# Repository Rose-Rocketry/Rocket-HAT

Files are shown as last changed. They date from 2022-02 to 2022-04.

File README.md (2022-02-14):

# Rocket-HAT
A Sensor Hat for a raspberry pi with: an IMU, Altimeter, and 5V power protection

# Usage
There are two jumpers on the board; J7 is for powering the hat through the PI. Otherwise, the HAT will get power from the battery while also powering the Pi. J9 is to
enable writing to the EEPROM after manufacture. This EEPROM is for matching with the Raspberry Pi foundation's specs.

There is also a solder bridge for the BNO055. This is in case we have an address conflict and need to change the address from 0x28 to 0x29.

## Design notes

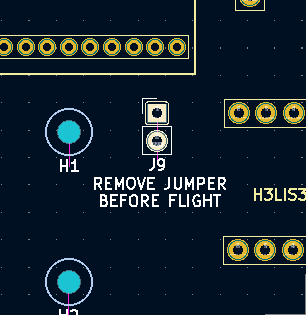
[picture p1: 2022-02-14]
rsc/J9 Screenshot.png

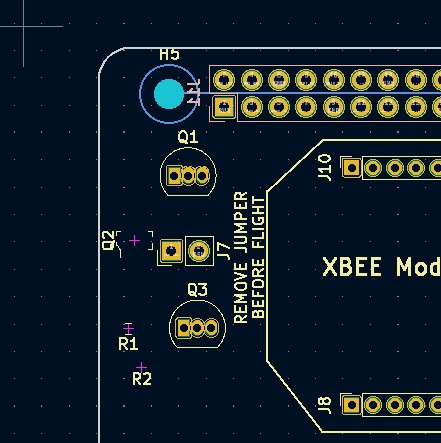
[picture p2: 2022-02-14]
rsc/J7 Screenshot.png

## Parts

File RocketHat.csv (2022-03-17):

Source: | C:\Users\armstrjj\Documents\Custom Electronics\RocketHat\RocketHat.kicad_sch
Date: | 3/3/2022 14:15
Tool: | Eeschema (6.0.0)
Generator: | C:\Program Files\KiCad\6.0\bin\scripting\plugins/bom_csv_grouped_by_value_with_fp.py
Component Count: | 28
Ref | Qnty | Value | Cmp name | Footprint | Description | Vendor | Already Listed
H1, H2, | 2 | MountingHole | MountingHole | MountingHole:MountingHole_2.2mm_M2 | Mounting Hole without connection
H3, H4, H5, H6, | 4 | MountingHole | MountingHole | MountingHole:MountingHole_2.7mm_M2.5 | Mounting Hole without connection
J1, J2, J4, | 3 | Conn_01x06_Female | Conn_01x06_Female | Connector_PinSocket_2.54mm:PinSocket_1x06_P2.54mm_Vertical | Generic connector, single row, 01x06, script generated (kicad-library-utils/schlib/autogen/connector/)
J3, | 1 | Conn_01x07_Female | Conn_01x07_Female | Connector_PinSocket_2.54mm:PinSocket_1x07_P2.54mm_Vertical | Generic connector, single row, 01x07, script generated (kicad-library-utils/schlib/autogen/connector/)
J5, | 1 | Conn_01x04_Female | Conn_01x04_Female | Connector_PinSocket_2.54mm:PinSocket_1x04_P2.54mm_Vertical | Generic connector, single row, 01x04, script generated (kicad-library-utils/schlib/autogen/connector/)
J6, | 1 | Conn_01x02_Female | Conn_01x02_Female | Connector_Wago:Wago_734-162_1x02_P3.50mm_Horizontal | Generic connector, single row, 01x02, script generated (kicad-library-utils/schlib/autogen/connector/) | OSTTE020104 On Shore Technology Inc. | Connectors, Interconnects | DigiKey
J7, J9, | 2 | Conn_01x02 | Conn_01x02 | Connector_PinHeader_2.54mm:PinHeader_1x02_P2.54mm_Vertical | Generic connector, single row, 01x02, script generated (kicad-library-utils/schlib/autogen/connector/) | QPC02SXGN-RC Sullins Connector Solutions | Connectors, Interconnects | DigiKey
J8, J10, | 2 | Conn_01x10_Female | Conn_01x10_Female | Connector_PinSocket_2.00mm:PinSocket_1x10_P2.00mm_Vertical | Generic connector, single row, 01x10, script generated (kicad-library-utils/schlib/autogen/connector/)
J11, | 1 | Raspberry_Pi_2_3 | Raspberry_Pi_2_3 | Connector_PinSocket_2.54mm:PinSocket_2x20_P2.54mm_Vertical | expansion header for Raspberry Pi 2 & 3
JP1, | 1 | SolderJumper_2_Open | SolderJumper_2_Open | Jumper:SolderJumper-2_P1.3mm_Open_TrianglePad1.0x1.5mm | Solder Jumper, 2-pole, open
Q1, Q3, | 2 | 2N3904 | 2N3904 | Package_TO_SOT_THT:TO-92_Inline | 0.2A Ic, 40V Vce, Small Signal NPN Transistor, TO-92 | 2N3904 Galco Industrial Electronics | Discrete Semiconductor Products | DigiKey Marketplace
Q2, | 1 | DMG2305UX-13 | DMG2305UX-13 | digikey-footprints:SOT-23-3 | MOSFET P-CH 20V 4.2A SOT23 | RQ5C035BCTCL Rohm Semiconductor | Discrete Semiconductor Products | DigiKey
R1, R3, | 2 | 10K | R_Small | Resistor_SMD:R_0603_1608Metric | Resistor, small symbol | See Next Link
R2, | 1 | 47K | R_Small | Resistor_SMD:R_0603_1608Metric | Resistor, small symbol | See Next Link
R4, | 1 | 10K 1% | R_Small | Resistor_SMD:R_0603_1608Metric | Resistor, small symbol | See Next Link
R5, R6, | 2 | 3.9K | R_Small | Resistor_SMD:R_0603_1608Metric | Resistor, small symbol | KIT-RMCF0603JT-13 Stackpole Electronics Inc | Kits | DigiKey
U1, | 1 | CAT24C128 | CAT24C128 | Package_SO:SOIC-8_3.9x4.9mm_P1.27mm | 128 kb CMOS Serial EEPROM, SOIC-8/TSSOP-8/DFN-8 | CAT24C128WI-GT3 onsemi | Integrated Circuits (ICs) | DigiKey Marketplace

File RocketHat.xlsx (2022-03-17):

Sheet: RocketHat
Source: | C:\Users\armstrjj\Documents\Custom Electronics\RocketHat\RocketHat.kicad_sch
Date: | 2022-03-03 14:15
Tool: | Eeschema (6.0.0)
Generator: | C:\Program Files\KiCad\6.0\bin\scripting\plugins/bom_csv_grouped_by_value_with_fp.py
Component Count: | 28
Ref | Qnty | Value | Cmp name | Footprint | Description | Vendor | Already Listed
H1, H2, | 2 | MountingHole | MountingHole | MountingHole:MountingHole_2.2mm_M2 | Mounting Hole without connection |  | Y
H3, H4, H5, H6, | 4 | MountingHole | MountingHole | MountingHole:MountingHole_2.7mm_M2.5 | Mounting Hole without connection |  | Y
J1, J2, J4, | 3 | Conn_01x06_Female | Conn_01x06_Female | Connector_PinSocket_2.54mm:PinSocket_1x06_P2.54mm_Vertical | Generic connector, single row, 01x06, script generated (kicad-library-utils/schlib/autogen/connector/) |  | Y
J3, | 1 | Conn_01x07_Female | Conn_01x07_Female | Connector_PinSocket_2.54mm:PinSocket_1x07_P2.54mm_Vertical | Generic connector, single row, 01x07, script generated (kicad-library-utils/schlib/autogen/connector/) |  | Y
J5, | 1 | Conn_01x04_Female | Conn_01x04_Female | Connector_PinSocket_2.54mm:PinSocket_1x04_P2.54mm_Vertical | Generic connector, single row, 01x04, script generated (kicad-library-utils/schlib/autogen/connector/) |  | Y
J6, | 1 | Conn_01x02_Female | Conn_01x02_Female | Connector_Wago:Wago_734-162_1x02_P3.50mm_Horizontal | Generic connector, single row, 01x02, script generated (kicad-library-utils/schlib/autogen/connector/) | OSTTE020104 On Shore Technology Inc. | Connectors, Interconnects | DigiKey (https://www.digikey.com/en/products/detail/on-shore-technology-inc/OSTTE020104/2351816)
J7, J9, | 2 | Conn_01x02 | Conn_01x02 | Connector_PinHeader_2.54mm:PinHeader_1x02_P2.54mm_Vertical | Generic connector, single row, 01x02, script generated (kicad-library-utils/schlib/autogen/connector/) | QPC02SXGN-RC Sullins Connector Solutions | Connectors, Interconnects | DigiKey (https://www.digikey.com/en/products/detail/sullins-connector-solutions/QPC02SXGN-RC/2618262)
J8, J10, | 2 | Conn_01x10_Female | Conn_01x10_Female | Connector_PinSocket_2.00mm:PinSocket_1x10_P2.00mm_Vertical | Generic connector, single row, 01x10, script generated (kicad-library-utils/schlib/autogen/connector/) |  | Y
J11, | 1 | Raspberry_Pi_2_3 | Raspberry_Pi_2_3 | Connector_PinSocket_2.54mm:PinSocket_2x20_P2.54mm_Vertical | expansion header for Raspberry Pi 2 & 3 |  | Y
JP1, | 1 | SolderJumper_2_Open | SolderJumper_2_Open | Jumper:SolderJumper-2_P1.3mm_Open_TrianglePad1.0x1.5mm | Solder Jumper, 2-pole, open |  | Y
Q1, Q3, | 2 | 2N3904 | 2N3904 | Package_TO_SOT_THT:TO-92_Inline | 0.2A Ic, 40V Vce, Small Signal NPN Transistor, TO-92 | 2N3904 Galco Industrial Electronics | Discrete Semiconductor Products | DigiKey Marketplace (https://www.digikey.com/en/products/detail/galco-industrial-electronics/2N3904/15657702)
Q2, | 1 | DMG2305UX-13 | DMG2305UX-13 | digikey-footprints:SOT-23-3 | MOSFET P-CH 20V 4.2A SOT23 | RQ5C035BCTCL Rohm Semiconductor | Discrete Semiconductor Products | DigiKey (https://www.digikey.com/en/products/detail/rohm-semiconductor/RQ5C035BCTCL/6573257)
R1, R3, | 2 | 10K | R_Small | Resistor_SMD:R_0603_1608Metric | Resistor, small symbol | See Next Link
R2, | 1 | 47K | R_Small | Resistor_SMD:R_0603_1608Metric | Resistor, small symbol | See Next Link
R4, | 1 | 10K 1% | R_Small | Resistor_SMD:R_0603_1608Metric | Resistor, small symbol | See Next Link
R5, R6, | 2 | 3.9K | R_Small | Resistor_SMD:R_0603_1608Metric | Resistor, small symbol | KIT-RMCF0603JT-13 Stackpole Electronics Inc | Kits | DigiKey (https://www.digikey.com/en/products/detail/stackpole-electronics-inc/KIT-RMCF0603JT-13/4916518)
U1, | 1 | CAT24C128 | CAT24C128 | Package_SO:SOIC-8_3.9x4.9mm_P1.27mm | 128 kb CMOS Serial EEPROM, SOIC-8/TSSOP-8/DFN-8 | DO NOT USE

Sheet: Final BOM
Item Name | Quanitity | Purchase Link | Price Per Unit | Itemized Cost | Total Order Cost
1608 Metric Resistor Book | 1 | KIT-RMCF0603JT-13 Stackpole Electronics Inc | Kits | DigiKey (https://www.digikey.com/en/products/detail/stackpole-electronics-inc/KIT-RMCF0603JT-13/4916518) | $26.96 | $26.96 | $50.07
RQ5C035BCTCL - P Channel Mosfet | 2 | RQ5C035BCTCL Rohm Semiconductor | Discrete Semiconductor Products | DigiKey (https://www.digikey.com/en/products/detail/rohm-semiconductor/RQ5C035BCTCL/6573257) | $0.45 | $0.90
NPN Transistor 40 | 25 | 2N3904 NTE Electronics, Inc | Discrete Semiconductor Products | DigiKey Marketplace (https://www.digikey.com/en/products/detail/nte-electronics-inc/2N3904/11648305) | $0.11 | $2.70
2-Wire Terminal Block 16-26 AWG | 2 | OSTTE020104 On Shore Technology Inc. | Connectors, Interconnects | DigiKey (https://www.digikey.com/en/products/detail/on-shore-technology-inc/OSTTE020104/2351816) | $0.76 | $1.52
Xbee Header Block Bag of 10 | 1 | Generic 2mm 10 Pin XBee Socket Header(pack of 10) - - Amazon.com (https://www.amazon.com/Generic-XBee-Socket-Header-pack/dp/B00OE92P88) | $7.99 | $7.99
Raspberry Pi Header Socket | 1 | Amazon.com: Adafruit 4079 2 x 20 Socket Riser Header for Raspberry Pi Hats and Bonnets : Electronics (https://www.amazon.com/Adafruit-Socket-Header-Raspberry-Bonnets/dp/B07PPD25MK) | $10.00 | $10.00

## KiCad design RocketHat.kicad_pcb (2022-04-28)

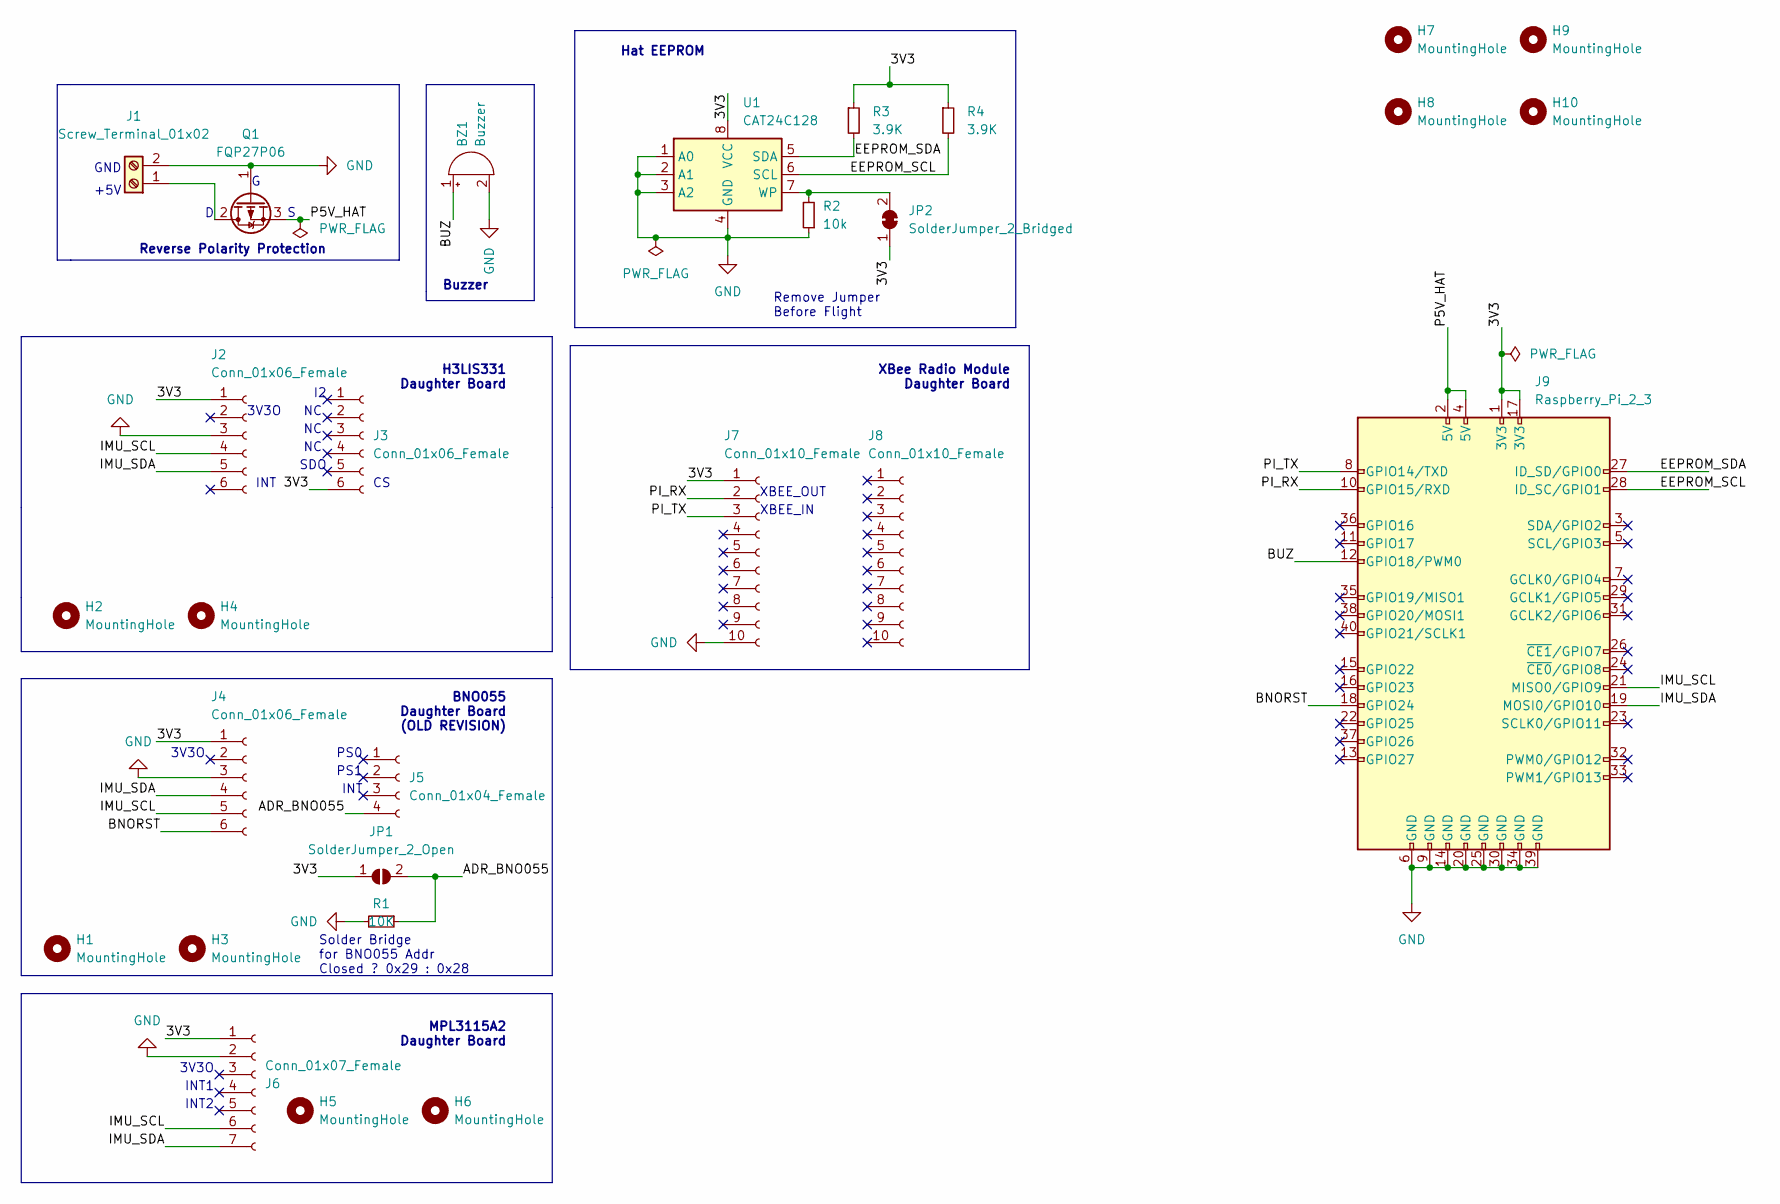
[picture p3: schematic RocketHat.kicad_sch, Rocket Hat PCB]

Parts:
BZ1: Buzzer; Buzzer_TDK_PS1240P02BT_D12.2mm_H6.5mm
H1, H2, H3, H4, H5, H6: MountingHole; MountingHole_2.2mm_M2
H7, H8, H9, H10: MountingHole; MountingHole_2.7mm_M2.5
J1: Screw_Terminal_01x02; TerminalBlock_Phoenix_MKDS-1,5-2_1x02_P5.00mm_Horizontal
J2, J3, J4: Conn_01x06_Female; PinSocket_1x06_P2.54mm_Vertical
J5: Conn_01x04_Female; PinSocket_1x04_P2.54mm_Vertical
J6: Conn_01x07_Female; PinSocket_1x07_P2.54mm_Vertical
J7, J8: Conn_01x10_Female; PinSocket_1x10_P2.00mm_Vertical
J9: Raspberry_Pi_2_3; PinSocket_2x20_P2.54mm_Vertical
JP1: SolderJumper_2_Open; SolderJumper-2_P1.3mm_Open_TrianglePad1.0x1.5mm
JP2: SolderJumper_2_Bridged; SolderJumper-2_P1.3mm_Bridged_RoundedPad1.0x1.5mm
Q1: FQP27P06; TO-220-3_Vertical
R1: 10K; R_Axial_DIN0204_L3.6mm_D1.6mm_P5.08mm_Horizontal
R2: 10k; R_Axial_DIN0204_L3.6mm_D1.6mm_P5.08mm_Horizontal
R3, R4: 3.9K; R_Axial_DIN0204_L3.6mm_D1.6mm_P5.08mm_Horizontal
U1: CAT24C128; SOIC-8_3.9x4.9mm_P1.27mm

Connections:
/3V3: J2.1, J3.6, J4.1, J6.1, J7.1, J9.1 (3V3), J9.17 (3V3), JP1.1 (A), JP2.1 (A), R3.1, R4.1, U1.8 (VCC)
/ADR_BNO055: J5.4, JP1.2 (B), R1.1
/BNORST: J4.6, J9.18 (GPIO24)
/BUZ: BZ1.1 (-), J9.12 (GPIO18/PWM0)
/EEPROM_SCL: J9.28 (ID_SC/GPIO1), R4.2, U1.6 (SCL)
/EEPROM_SDA: J9.27 (ID_SD/GPIO0), R3.2, U1.5 (SDA)
/IMU_SCL: J2.4, J4.5, J6.6, J9.21 (MISO0/GPIO9)
/IMU_SDA: J2.5, J4.4, J6.7, J9.19 (MOSI0/GPIO10)
/P5V_HAT: J9.2 (5V), J9.4 (5V), Q1.3 (S)
/PI_RX: J7.2, J9.10 (GPIO15/RXD)
/PI_TX: J7.3, J9.8 (GPIO14/TXD)
GND: BZ1.2 (+), J1.2, J2.3, J4.3, J6.2, J7.10, J9.6 (GND), J9.9 (GND), J9.14 (GND), J9.20 (GND), J9.25 (GND), J9.30 (GND), J9.34 (GND), J9.39 (GND), Q1.1 (G), R1.2, R2.1, U1.1 (A0), U1.2 (A1), U1.3 (A2), U1.4 (GND)
unnamed: J1.1, Q1.2 (D)
unnamed: JP2.2 (B), R2.2, U1.7 (WP)

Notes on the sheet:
Buzzer
XBEE_IN
PS1
Reverse Polarity Protection
INT
XBEE_OUT
MPL3115A2 Daughter Board
INT1
3V3O
GND
XBee Radio Module Daughter Board
Remove Jumper Before Flight
H3LIS331 Daughter Board
BNO055 Daughter Board (OLD REVISION)
+5V
Hat EEPROM
Solder Bridge for BNO055 Addr Closed ? 0x29 : 0x28
INT2
PS0
SDO

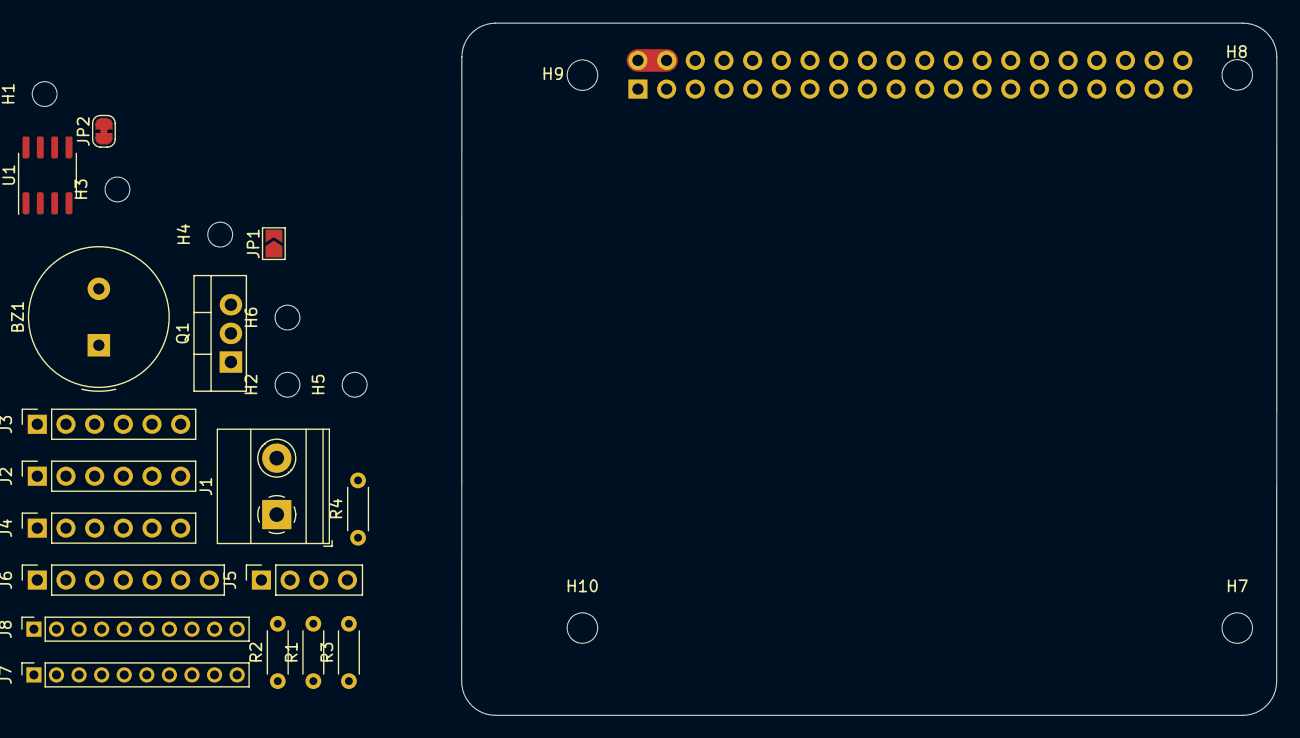
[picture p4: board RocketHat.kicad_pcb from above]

Board: 2 copper layers, 72.2 x 61.3 mm, 28 parts (1 on the bottom side), 14 nets.

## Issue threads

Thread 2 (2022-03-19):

Size Metric 1608 Resistors are Too Small

Lainkai, 2022-03-19:
Need to upsize the resistors to something we can buy from the parts room.
TODO: Find what sizes the parts room has.

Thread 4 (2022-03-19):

Move XBee Mount to An Edge

Lainkai, 2022-03-19:
The Xbee mount should be close to an edge w/o obstruction so that the SMA connector has unobstructed access to the device.

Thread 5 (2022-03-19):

Remove Power Protection Circuit

Lainkai, 2022-03-19:
In stead of a back flow power protection circuit, we should implement a reverse polarity protection diode. This is because we should only use the power terminal if we are flight ready. If we need to implement more safety features please write them in the comments.

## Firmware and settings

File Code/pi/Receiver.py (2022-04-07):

#!/usr/bin/env python3
# -*- coding: utf-8 -*-

#
# SPDX-License-Identifier: GPL-3.0
#
# GNU Radio Python Flow Graph
# Title: Receiver
# Author: me
# GNU Radio version: 3.8.2.0

from distutils.version import StrictVersion

if __name__ == '__main__':
    import ctypes
    import sys
    if sys.platform.startswith('linux'):
        try:
            x11 = ctypes.cdll.LoadLibrary('libX11.so')
            x11.XInitThreads()
        except:
            print("Warning: failed to XInitThreads()")

from PyQt5 import Qt
from gnuradio import qtgui
from gnuradio.filter import firdes
import sip
from gnuradio import blocks
from gnuradio import gr
import sys
import signal
from argparse import ArgumentParser
from gnuradio.eng_arg import eng_float, intx
from gnuradio import eng_notation
from gnuradio.qtgui import Range, RangeWidget
import fcdproplus

from gnuradio import qtgui

class Receiver(gr.top_block, Qt.QWidget):

    def __init__(self):
        gr.top_block.__init__(self, "Receiver")
        Qt.QWidget.__init__(self)
        self.setWindowTitle("Receiver")
        qtgui.util.check_set_qss()
        try:
            self.setWindowIcon(Qt.QIcon.fromTheme('gnuradio-grc'))
        except:
            pass
        self.top_scroll_layout = Qt.QVBoxLayout()
        self.setLayout(self.top_scroll_layout)
        self.top_scroll = Qt.QScrollArea()
        self.top_scroll.setFrameStyle(Qt.QFrame.NoFrame)
        self.top_scroll_layout.addWidget(self.top_scroll)
        self.top_scroll.setWidgetResizable(True)
        self.top_widget = Qt.QWidget()
        self.top_scroll.setWidget(self.top_widget)
        self.top_layout = Qt.QVBoxLayout(self.top_widget)
        self.top_grid_layout = Qt.QGridLayout()
        self.top_layout.addLayout(self.top_grid_layout)

        self.settings = Qt.QSettings("GNU Radio", "Receiver")

        try:
            if StrictVersion(Qt.qVersion()) < StrictVersion("5.0.0"):
                self.restoreGeometry(self.settings.value("geometry").toByteArray())
            else:
                self.restoreGeometry(self.settings.value("geometry"))
        except:
            pass

        ##################################################
        # Variables
        ##################################################
        self.volume = volume = 50
        self.variable_0 = variable_0 = 0
        self.samp_rate = samp_rate = 32e3
        self.center_freq = center_freq = 425e6

        ##################################################
        # Blocks
        ##################################################
        self._volume_range = Range(0, 100, 1, 50, 200)
        self._volume_win = RangeWidget(self._volume_range, self.set_volume, 'volume', "counter_slider", float)
        self.top_grid_layout.addWidget(self._volume_win)
        self.qtgui_time_sink_x_0 = qtgui.time_sink_f(
            102424, #size
            samp_rate, #samp_rate
            "", #name
            1 #number of inputs
        )
        self.qtgui_time_sink_x_0.set_update_time(0.10)
        self.qtgui_time_sink_x_0.set_y_axis(-1, 1)

        self.qtgui_time_sink_x_0.set_y_label('Amplitude', "")

        self.qtgui_time_sink_x_0.enable_tags(True)
        self.qtgui_time_sink_x_0.set_trigger_mode(qtgui.TRIG_MODE_FREE, qtgui.TRIG_SLOPE_POS, 0.0, 0, 0, "")
        self.qtgui_time_sink_x_0.enable_autoscale(True)
        self.qtgui_time_sink_x_0.enable_grid(False)
        self.qtgui_time_sink_x_0.enable_axis_labels(True)
        self.qtgui_time_sink_x_0.enable_control_panel(False)
        self.qtgui_time_sink_x_0.enable_stem_plot(False)


        labels = ['Signal 1', 'Signal 2', 'Signal 3', 'Signal 4', 'Signal 5',
            'Signal 6', 'Signal 7', 'Signal 8', 'Signal 9', 'Signal 10']
        widths = [1, 1, 1, 1, 1,
            1, 1, 1, 1, 1]
        colors = ['blue', 'red', 'green', 'black', 'cyan',
            'magenta', 'yellow', 'dark red', 'dark green', 'dark blue']
        alphas = [1.0, 1.0, 1.0, 1.0, 1.0,
            1.0, 1.0, 1.0, 1.0, 1.0]
        styles = [1, 1, 1, 1, 1,
            1, 1, 1, 1, 1]
        markers = [-1, -1, -1, -1, -1,
            -1, -1, -1, -1, -1]


        for i in range(1):
            if len(labels[i]) == 0:
                self.qtgui_time_sink_x_0.set_line_label(i, "Data {0}".format(i))
            else:
                self.qtgui_time_sink_x_0.set_line_label(i, labels[i])
            self.qtgui_time_sink_x_0.set_line_width(i, widths[i])
            self.qtgui_time_sink_x_0.set_line_color(i, colors[i])
            self.qtgui_time_sink_x_0.set_line_style(i, styles[i])
            self.qtgui_time_sink_x_0.set_line_marker(i, markers[i])
            self.qtgui_time_sink_x_0.set_line_alpha(i, alphas[i])

        self._qtgui_time_sink_x_0_win = sip.wrapinstance(self.qtgui_time_sink_x_0.pyqwidget(), Qt.QWidget)
        self.top_grid_layout.addWidget(self._qtgui_time_sink_x_0_win)
        self.fcdproplus_fcdproplus_0 = fcdproplus.fcdproplus('',1)
        self.fcdproplus_fcdproplus_0.set_lna(1)
        self.fcdproplus_fcdproplus_0.set_mixer_gain(1)
        self.fcdproplus_fcdproplus_0.set_if_gain(1)
        self.fcdproplus_fcdproplus_0.set_freq_corr(0)
        self.fcdproplus_fcdproplus_0.set_freq(99900000)
        self._center_freq_range = Range(1, 1e9, 1, 425e6, 200)
        self._center_freq_win = RangeWidget(self._center_freq_range, self.set_center_freq, 'center_freq', "counter_slider", float)
        self.top_grid_layout.addWidget(self._center_freq_win)
        self.blocks_multiply_const_vxx_0_0 = blocks.multiply_const_cc(1)
        self.blocks_moving_average_xx_0 = blocks.moving_average_ff(1000000, 1e-3, 4000, 1)
        self.blocks_file_sink_0 = blocks.file_sink(gr.sizeof_float*1, '/home/pi/datafile-1.dat', False)
        self.blocks_file_sink_0.set_unbuffered(False)
        self.blocks_complex_to_mag_squared_0 = blocks.complex_to_mag_squared(1)



        ##################################################
        # Connections
        ##################################################
        self.connect((self.blocks_complex_to_mag_squared_0, 0), (self.blocks_moving_average_xx_0, 0))
        self.connect((self.blocks_moving_average_xx_0, 0), (self.blocks_file_sink_0, 0))
        self.connect((self.blocks_moving_average_xx_0, 0), (self.qtgui_time_sink_x_0, 0))
        self.connect((self.blocks_multiply_const_vxx_0_0, 0), (self.blocks_complex_to_mag_squared_0, 0))
        self.connect((self.fcdproplus_fcdproplus_0, 0), (self.blocks_multiply_const_vxx_0_0, 0))


    def closeEvent(self, event):
        self.settings = Qt.QSettings("GNU Radio", "Receiver")
        self.settings.setValue("geometry", self.saveGeometry())
        event.accept()

    def get_volume(self):
        return self.volume

    def set_volume(self, volume):
        self.volume = volume

    def get_variable_0(self):
        return self.variable_0

    def set_variable_0(self, variable_0):
        self.variable_0 = variable_0

    def get_samp_rate(self):
        return self.samp_rate

    def set_samp_rate(self, samp_rate):
        self.samp_rate = samp_rate
        self.qtgui_time_sink_x_0.set_samp_rate(self.samp_rate)

    def get_center_freq(self):
        return self.center_freq

    def set_center_freq(self, center_freq):
        self.center_freq = center_freq





def main(top_block_cls=Receiver, options=None):

    if StrictVersion("4.5.0") <= StrictVersion(Qt.qVersion()) < StrictVersion("5.0.0"):
        style = gr.prefs().get_string('qtgui', 'style', 'raster')
        Qt.QApplication.setGraphicsSystem(style)
    qapp = Qt.QApplication(sys.argv)

    tb = top_block_cls()

    tb.start()

    tb.show()

    def sig_handler(sig=None, frame=None):
        Qt.QApplication.quit()

    signal.signal(signal.SIGINT, sig_handler)
    signal.signal(signal.SIGTERM, sig_handler)

    timer = Qt.QTimer()
    timer.start(500)
    timer.timeout.connect(lambda: None)

    def quitting():
        tb.stop()
        tb.wait()

    qapp.aboutToQuit.connect(quitting)
    qapp.exec_()

if __name__ == '__main__':
    main()

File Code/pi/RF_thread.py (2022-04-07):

#!/usr/bin/env python3
# -*- coding: utf-8 -*-

#
# SPDX-License-Identifier: GPL-3.0
#
# GNU Radio Python Flow Graph
# Title: reciverfilesink2.3
# Author: pi
# GNU Radio version: 3.8.2.0

import time
from gnuradio import blocks
from gnuradio import digital
from gnuradio import gr
from gnuradio.filter import firdes
import sys
import signal
from argparse import ArgumentParser
from gnuradio.eng_arg import eng_float, intx
from gnuradio import eng_notation
from gnuradio.fft import logpwrfft
import fcdproplus


class RF_Logging(gr.top_block):

    def __init__(self):
        gr.top_block.__init__(self, "reciverfilesink2.3")

        ##################################################
        # Variables
        ##################################################
        self.samp_rate = samp_rate = 192000
        self.bpak = bpak = digital.constellation_bpsk().base()

        ##################################################
        # Blocks
        ##################################################
        self.logpwrfft_x_0 = logpwrfft.logpwrfft_c(
            sample_rate=samp_rate,
            fft_size=1024,
            ref_scale=2,
            frame_rate=30,
            avg_alpha=1.0,
            average=False)
        self.fcdproplus_fcdproplus_0 = fcdproplus.fcdproplus('',1)
        self.fcdproplus_fcdproplus_0.set_lna(1)
        self.fcdproplus_fcdproplus_0.set_mixer_gain(1)
        self.fcdproplus_fcdproplus_0.set_if_gain(1)
        self.fcdproplus_fcdproplus_0.set_freq_corr(0)
        self.fcdproplus_fcdproplus_0.set_freq(426000000)
        self.digital_diff_decoder_bb_0 = digital.diff_decoder_bb(2)
        self.digital_costas_loop_cc_0 = digital.costas_loop_cc(12000, 2, True)
        self.digital_constellation_decoder_cb_0 = digital.constellation_decoder_cb(bpak)
        self.blocks_uchar_to_float_0 = blocks.uchar_to_float()
        self.blocks_moving_average_xx_0 = blocks.moving_average_ff(1000, 1, 4000, 1)
        self.blocks_max_xx_0 = blocks.max_ff(1024, 1)
        self.blocks_file_sink_1 = blocks.file_sink(gr.sizeof_float*1, '/home/pi/datafile-11.dat', False)
        self.blocks_file_sink_1.set_unbuffered(False)
        self.blocks_file_sink_0 = blocks.file_sink(gr.sizeof_float*1, '/home/pi/datafile-1.dat', False)
        self.blocks_file_sink_0.set_unbuffered(False)



        ##################################################
        # Connections
        ##################################################
        self.connect((self.blocks_max_xx_0, 0), (self.blocks_moving_average_xx_0, 0))
        self.connect((self.blocks_moving_average_xx_0, 0), (self.blocks_file_sink_0, 0))
        self.connect((self.blocks_uchar_to_float_0, 0), (self.blocks_file_sink_1, 0))
        self.connect((self.digital_constellation_decoder_cb_0, 0), (self.digital_diff_decoder_bb_0, 0))
        self.connect((self.digital_costas_loop_cc_0, 0), (self.digital_constellation_decoder_cb_0, 0))
        self.connect((self.digital_diff_decoder_bb_0, 0), (self.blocks_uchar_to_float_0, 0))
        self.connect((self.fcdproplus_fcdproplus_0, 0), (self.digital_costas_loop_cc_0, 0))
        self.connect((self.fcdproplus_fcdproplus_0, 0), (self.logpwrfft_x_0, 0))
        self.connect((self.logpwrfft_x_0, 0), (self.blocks_max_xx_0, 0))


    def get_samp_rate(self):
        return self.samp_rate

    def set_samp_rate(self, samp_rate):
        self.samp_rate = samp_rate
        self.logpwrfft_x_0.set_sample_rate(self.samp_rate)

    def get_bpak(self):
        return self.bpak

    def set_bpak(self, bpak):
        self.bpak = bpak





def main(top_block_cls=RF_Logging, options=None):
    tb = top_block_cls()

    def sig_handler(sig=None, frame=None):
        tb.stop()
        tb.wait()

        sys.exit(0)

    signal.signal(signal.SIGINT, sig_handler)
    signal.signal(signal.SIGTERM, sig_handler)

    tb.start()

    try:
        time.sleep(80)
    except EOFError:
        pass
    end = time.time()
    tb.stop()
    tb.wait()


if __name__ == '__main__':
   start = time.time() 
   main()

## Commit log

2022-02-14 Uploaded KiCad Files
    [RocketHat.kicad_pcb, RocketHat.kicad_sch]
2022-02-14 Fixed Missing Line
    [RocketHat.kicad_pcb]
2022-02-14 Added Resources
    [RocketHat.kicad_pcb]
2022-02-14 Cleaned Up Layouts A Little
    [RocketHat.kicad_pcb]
2022-02-14 Fixed All DRC Errors
    [RocketHat.kicad_pcb, RocketHat.kicad_sch]
2022-02-14 Fixed Segments
    [RocketHat.kicad_pcb]
2022-02-14 Fixed location of Mounting Holes
    [RocketHat.kicad_pcb]
2022-02-14 Generated Gerbers for Curiosity
    [RocketHat-B_Cu.gbr, RocketHat-B_Mask.gbr, RocketHat-B_Paste.gbr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]
2022-02-15 Set Mounting Holes 1&2 to M2
    [RocketHat.kicad_pcb, RocketHat.kicad_sch]
2022-02-15 Added Flood Zone
    [RocketHat.kicad_pcb, RocketHat.kicad_sch]
2022-02-21 Added Gerber Zip
    [RocketHat-B_Cu.gbr, RocketHat-B_Mask.gbr, RocketHat-B_Paste.gbr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]
2022-02-21 Smol Board
    [RocketHat-B_Cu.gbr, RocketHat-B_Mask.gbr, RocketHat-B_Paste.gbr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]
2022-02-21 Even SMOLLER Board
    [RocketHat-B_Cu.gbr, RocketHat-B_Mask.gbr, RocketHat-B_Paste.gbr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]
2022-02-21 Smol Board + Title Block
    [RocketHat-B_Cu.gbr, RocketHat-B_Mask.gbr, RocketHat-B_Paste.gbr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]
2022-03-08 Rose Rocketry Raspy Rasputin github account created 03/08/2022 Added the updated IMU code
2022-03-08 added imu code
2022-03-10 Backups & Excel
    [RocketHat.xlsx]
2022-03-11 fixed the accel_p error since it isn't needed anymore
    [i2c_read_test.py]
2022-03-14 Added Final BOM Table
    [RocketHat.csv, RocketHat.xlsx]
2022-03-20 Version 1.1.0
    [RocketHat.kicad_pcb, RocketHat.kicad_sch]
2022-03-20 Added Graphic
    [RocketHat.kicad_pcb]
2022-03-24 PCB Updates
    [RocketHat.kicad_pcb, RocketHat.kicad_sch]
2022-03-25 Cool Thicc Lines
    [RocketHat.kicad_pcb, RocketHat.kicad_sch]
2022-03-25 Fixed DRC
    [RocketHat.kicad_pcb]
2022-04-02 Fixed Inverted Layout
    [RocketHat.kicad_pcb, RocketHat.kicad_sch]
2022-04-03 Passed DRC With 1.1.1
    [RocketHat.kicad_pcb, RocketHat.kicad_sch]
2022-04-21 Added Buzzer
    [RocketHat.kicad_sch]
2022-04-22 Updated EEPROM WP
    [RocketHat.kicad_sch]
2022-04-22 Updated Schematics and Footprints
    [RocketHat.kicad_pcb, RocketHat.kicad_sch]
2022-04-22 Added Mounting Holes for all sensors
    [RocketHat.kicad_pcb, RocketHat.kicad_sch]
2022-04-28 Cleared Layout
    [RocketHat.kicad_pcb, RocketHat.kicad_sch]
2022-04-28 Closed KiCad

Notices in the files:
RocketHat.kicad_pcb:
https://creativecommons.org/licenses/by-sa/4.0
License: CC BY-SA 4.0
